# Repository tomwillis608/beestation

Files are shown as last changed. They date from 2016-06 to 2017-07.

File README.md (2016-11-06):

# beestation
Repo for wireless bee monitoring station experiments.

Currently embarassing hacking at simple Arduino and LAMP projects.  My first Arduino project.

ardunio/ - contains sketch for listening to sensors and sending the readings back to a PHP over WiFi.
server/ - contains php and mysql to use on your LAMP server

Done:
 * Add hardware watchdog circuit based on 555 chip. Something between my wireless network and the TCP connect calls locks up 5x a day.
 * Add multiple One-Wire sensors

To Do:
 * Add power-saving features
 * Add audio level and pitch sensors
 * Add weight sensors

Pondering
 * Add camera facing hive entrance 

-Tom Willis
Hacking Arduino for bees

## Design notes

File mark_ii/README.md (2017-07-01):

**beestation**

Repo for wireless bee monitoring station **Mark II** experiments.

*LAMP* folder for backend PHP and SQL manipulation of the data, plus web discplay of the data
*pi* folder for Raspberry Pi middle layer, receiving RF transmissions from the probes and sending data via HTTP to the LAMP backend
*arduino* folder for sketches, diagrams and pix about the wireless measurement probes

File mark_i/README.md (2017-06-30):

**beestation**

Repo for wireless bee monitoring station **Mark I** experiments.

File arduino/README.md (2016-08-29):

# beestation/arduino

Arduino sketch for wireless beehive monitoring station experiments

Currently embarassing hacking at simple Arduino and LAMP projects

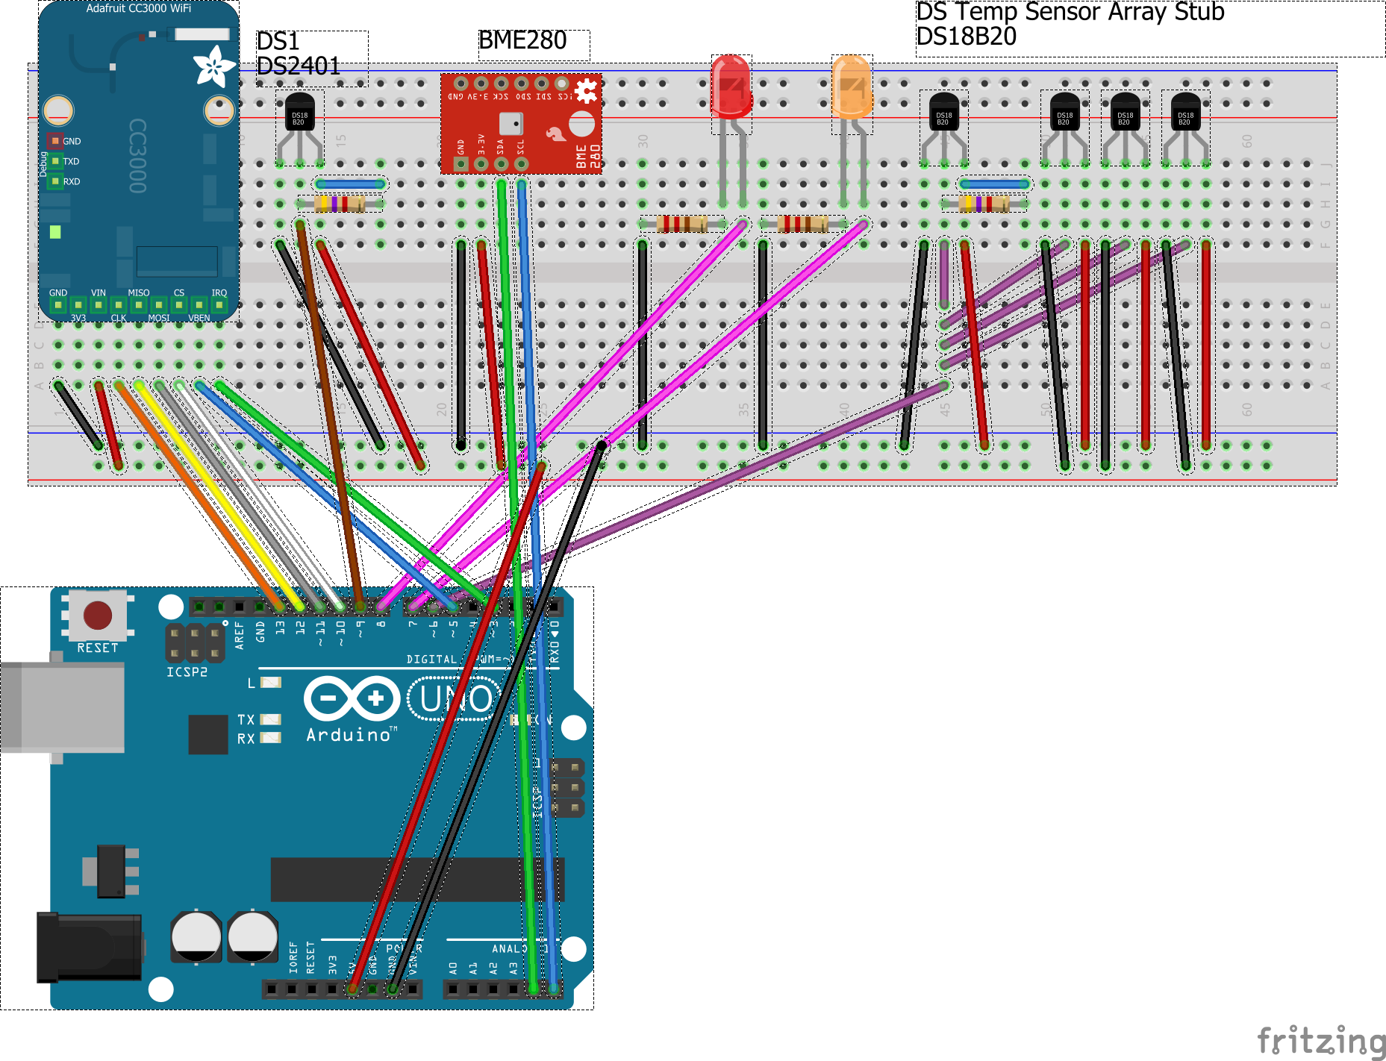
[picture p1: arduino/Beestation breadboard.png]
[]

beestation.ino - contains sketch for listening to a sensor and sending the readings back to a PHP over WiFi

beestation_breadboard.png - Frizing breadboard diagram for the kit (Note, I am actually using an Adafruit BME280 breakout, not the Sparkfun one shown in the image.

You must create your own MyCommon/mynetwork.h file that defines your own network secrets in your Arduino libraries folder. This must contain these macros, with the dummy values replaced with your own.
```C++
// Mynetwork.h
#define WEB_SERVER_IP_COMMAS 192, 168, 1, 1
#define WEB_SERVER_IP_DOTS   "192.168.1.1"
#define WLAN_SSID       "Your Network SSID"
#define WLAN_PASS       "Your Network Passcode"
```

I'm using the Visual Micro extension for Visual Studio because I like single-step debugging but you can use the sketch without all the Visual Studio clutter.

## THANKS:
Thanks to Marc-Oliver Schwartz for this excellent walkthrough of creating an Arduino weather station, with testing as you go.  I based much of this on his example. 
https://www.openhomeautomation.net/arduino-wifi-cc3000/
https://learn.adafruit.com/wifi-weather-station-arduino-cc3000/introduction

## Sensors:
* BME280 - Pressure, Humidity and Temperature. This will be measured outside the hive, at the board.
* DS2401 - Silicon serial number.  Unique ID for this kit. 

## Hardware watchdog
* NE555-based watchdog timer added to reset the Arduino if any of the code locks up
  
## To do:
* Add DS18B20 temperature sensors, in beeproof sleeves, to measure inside the hive
* Build hive sound volume level meter, in beeproof sleeve
* Harden wireless code
* Use built-in WTD watchdog for power-saving sleep
* On server end, collect local temperature and pressure from WU or other API as control values

-Tom Willis

Hacking Arduino for bees

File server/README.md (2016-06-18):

# beestation/arduino/server

PHP and MySQL for wireless bee monitoring station experiments

Currently embarassing hacking at simple Arduino and LAMP projects

php - php scripts to add sensor data to the tables and to display the data
mysql - MySQL code to create the tables needed to store the data

-Tom Willis
Hacking Arduino for bees

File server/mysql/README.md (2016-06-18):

# beestation/arduino/server/mysql

MySQL commands for wireless bee monitoring station experiments

Currently embarassing hacking at simple Arduino and LAMP projects

create_sensor_table.mysql - command to create the 'dht22' table for recording temperature and humidity sensor readings 

create_info_table.mysql - command to create the 'beestation' table for recording information about the monitoring station itself, e.g. when it starts up 

-Tom Willis
Hacking Arduino for bees

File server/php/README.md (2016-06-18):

# beestation/arduino/server/php

PHP scripts for wireless bee monitoring station experiments

Currently embarassing hacking at simple Arduino and LAMP projects

The add_* PHP scripts are called by the Arduino monitoring station to record data in MySQL tables

add_info.php - Add startup information about the monitoring station to the database
add_data.php - Add sensor data from the monitoring station to the database

The view_* PHP scripts are useful for viewing the data in a simple way

view_info.php - See the data about the monitoring station behavior
view_data.php - See the sensor data collected from the monitoring station

All of the four scripts above include "dbconnect.php", which contains database secrets.

You must create your own dbconnect.php file that defines your own database secrets, using the dbconnect_template.php as an example, to define your MySQL username, password, server and database name.

-Tom Willis
Hacking Arduino for bees

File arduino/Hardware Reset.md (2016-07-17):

# Hardware reset watchdog timer for Arduino

Somewhere in the interaction of my wireless network, which has some instabilities I have not yet sorted out, and the CC3300 WiFi on my Arduino beestation, I am getting lockups of the sketch, typically in the TCP conenct calls.  This seems to happend about four times a day, on average. The built-in AVR watch dog timer does not consistently reset the Arduino when this happens.  I decided to add a hardware watchdog to suppliment and perhaps replace the built-in AVR watchdog.  (TO DO: repurpose the AVR WTD to put the system to sleep in between measurements to conserve power.)

Thankfully, there are several useful articles on creating a hardware watchdog using a NE555 timer chip, including:
* http://www.practicalarduino.com/news/id/471
* http://forum.arduino.cc/index.php?topic=55041.0
* http://arduino.stackexchange.com/questions/7994/resetting-an-arduino-with-a-timer
* https://github.com/mattbornski/Arduino-Watchdog-Circuit
* https://www.circuitlab.com/circuit/cc9d7s/arduino-555-watchdog-circuit/
* http://www.playwitharduino.com/?p=291

I followed the cicruit design from http://www.playwitharduino.com/?p=291 and experimented with different capacitor values for C1, which changed the charge time as predicted by the forumlas provided in that article. I ended up settling with the 220uF suggested by the author since it was long enough but not as long at the 470uF provided. 

One of several 555 calculators is here: http://www.csgnetwork.com/ne555timer2calc.html

The 555 chip is new to me, so I enjoyed reading the 555 site http://www.555-timer-circuits.com/, especially the FAQ at http://www.555-timer-circuits.com/common-mistakes.html

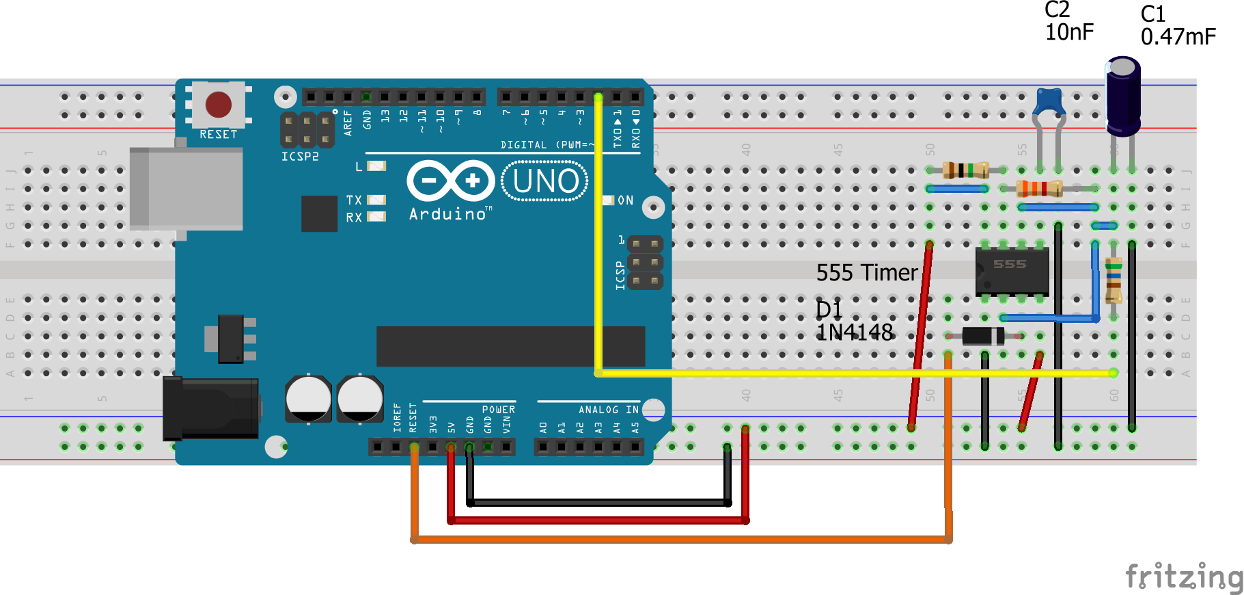
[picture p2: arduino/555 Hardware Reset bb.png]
[]

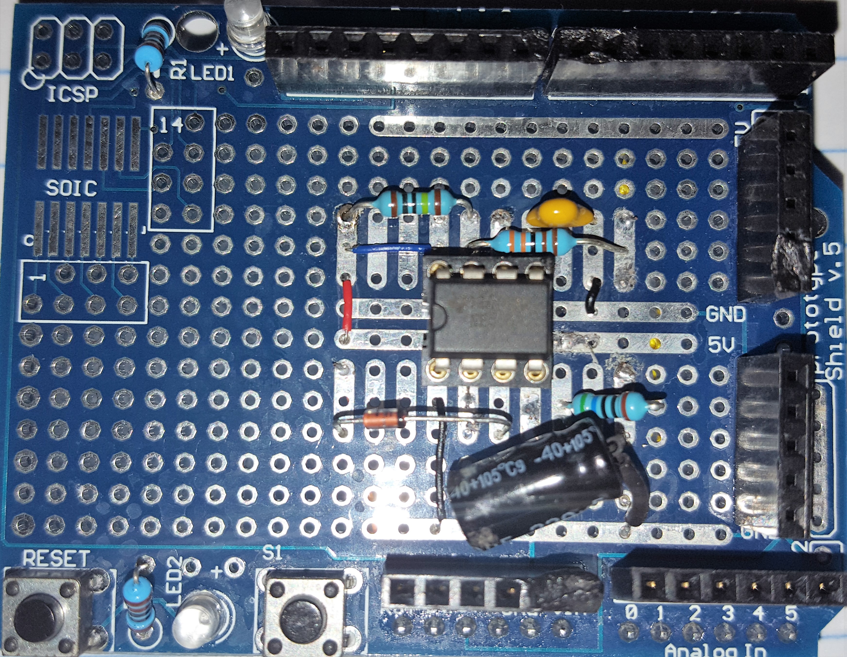
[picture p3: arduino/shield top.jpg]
[]

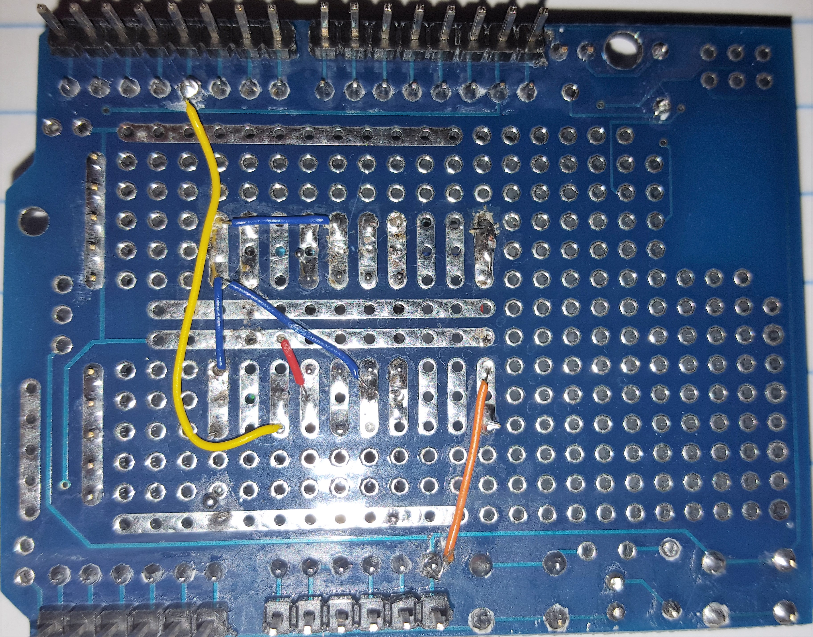
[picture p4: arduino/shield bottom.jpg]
[]

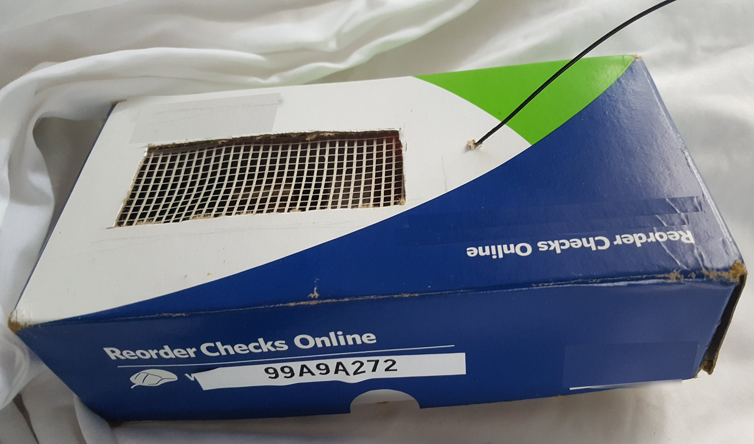
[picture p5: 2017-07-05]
mark_ii/prototype in-hive container for probes.jpg

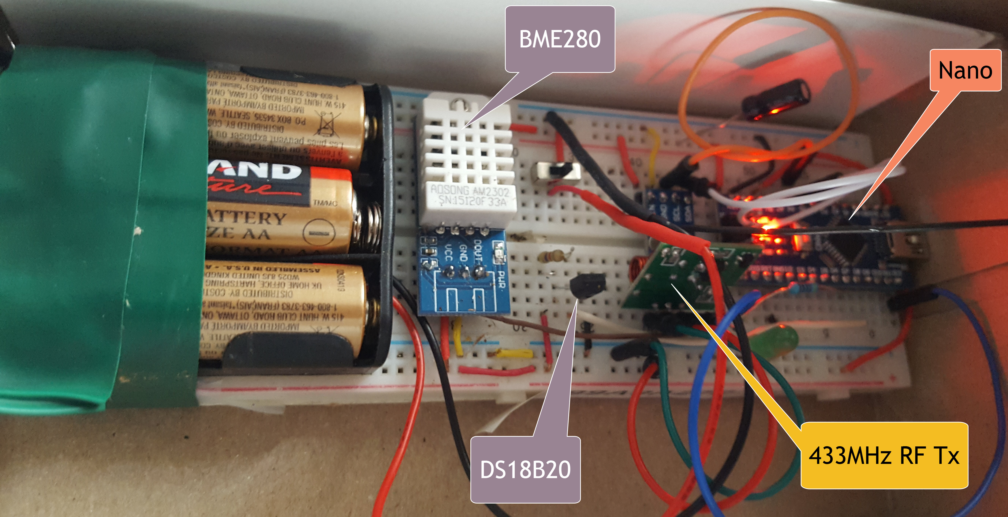
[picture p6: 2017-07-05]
mark_ii/Mark II Multiprobe Tx.jpg

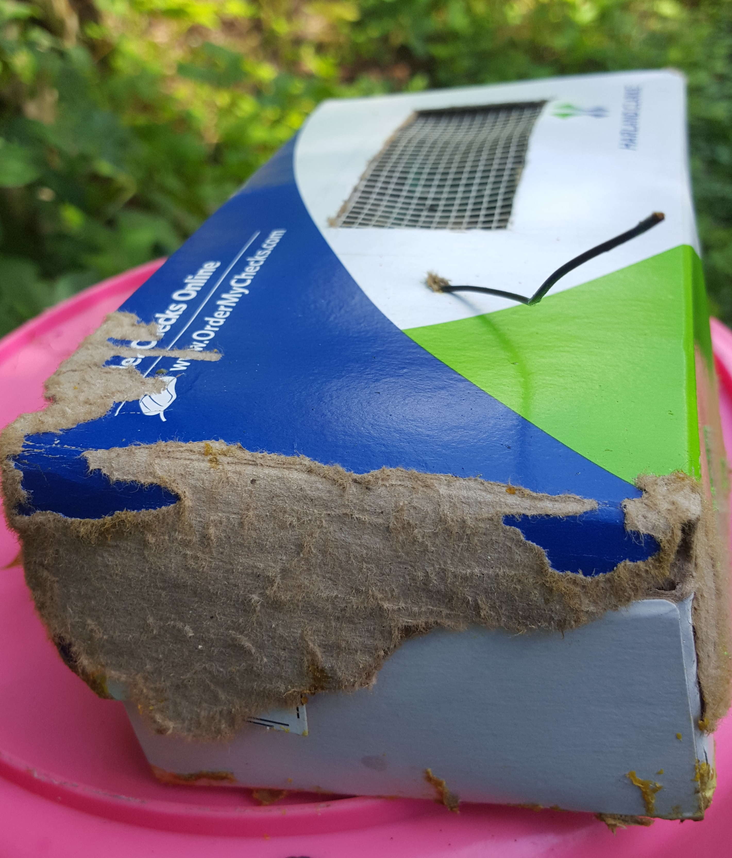
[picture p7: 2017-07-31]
mark_ii/mark ii nibbles.jpg

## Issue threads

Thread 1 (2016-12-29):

System doesn't work when temperature less than 0 degrees Celcius

tomwillis608, 2016-12-29:
When the temperature of the beehive drops below freezing, the system constantly reboots, connects to the web server but never reports and temperature measurements.

tomwillis608, 2016-12-29:
The temperature conversion routine for the DS18B20 sensors does not take into account the sign bit.

Closed 2016-12-29.

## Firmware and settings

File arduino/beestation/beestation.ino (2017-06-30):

/*
*  WiFi beekeeping monitor station with Arduino,
*  BME 280 temperature-pressure-humidity sensor,
*  Maxim DS2401 silicon serial number,
*  Maxim DS18B20 temperature sensors,
*  & the CC3000 chip WiFi.
*
*  Part of the code is based on the work done by Adafruit on the CC3000 chip & the DHT11 sensor.
*  Based in part on dht11/cc3300 weatherstation written by Marco Schwartz for Open Home Automation.
*  Based in part on OneWire/DS18B20 sample code from the OneWire library.
*  Lots of ideas taken from the many helpful posts in the community online.
*
*  Purpose:
*   Sends data to LAMP backend with HTTP GETs
*   Be stable over all conditions (Hardware reset cicruit currently required)
*
*  To Do:
*   More sensors, besides temperature. <<In Progress>>
*   Better network recovery code - I saw some ideas online
*   Powersaving by sleeping instead of waiting
*   Reduce code size
*
*/

#define USE_DHT 0
#define USE_CC3300 01
#define USE_DS2401 1
#define USE_DS18B20 1
#define USE_BME 1
#define MY_DEBUG 0

// Include required libraries
#include <Adafruit_CC3000.h> // wifi library
#include <SPI.h> // how to talk to adafruit cc3300 board
#include <OneWire.h> // PJRC OneWire library to read DS 1-Wire sensors, like DS2401 and DS18B20
					 // http://www.pjrc.com/teensy/td_libs_OneWire.html
#if USE_BME 
// Using I2C protocol
#include <Adafruit_BME280.h>
#endif // USE_BME

#include <avr/wdt.h> // Watchdog timer

#include <mynetwork.h> // defines network secrets and addresses
// WLAN_SSID
// WLAN_PASS
// WEB_SERVER_IP_COMMAS 
// WEB_SERVER_IP_DOTS 

// WiFi network 
#define WLAN_SECURITY   WLAN_SEC_WPA2

// Define CC3000 chip pins (WiFi board)
#define ADAFRUIT_CC3000_IRQ   3
#define ADAFRUIT_CC3000_VBAT  5
#define ADAFRUIT_CC3000_CS    10

// DS2401 bus pin
#define DS2401PIN 9
#define DS18B20PIN 6

// Create global CC3000 instance
Adafruit_CC3000 gCc3000 = Adafruit_CC3000(ADAFRUIT_CC3000_CS,
	ADAFRUIT_CC3000_IRQ,
	ADAFRUIT_CC3000_VBAT,
	SPI_CLOCK_DIVIDER);

#if USE_BME
Adafruit_BME280 gBme280; // I2C
// Variables to be exposed 
int gHumidity = 0;
int gPressure = 0;
int gTemperature = 0; 
#endif // USE_BME

#if USE_DS18B20
OneWire gDs(DS18B20PIN);
int gDevices;
#define DS_COUNT 10
byte gDsAddrs[DS_COUNT][8];
// Use array for DS18B20 temperatures and simplify HTTP printout code
int gDsTemps[DS_COUNT];
#endif // USE_DS18B20

// PHP server on backend
const char gWebServer[] = WEB_SERVER_IP_DOTS; // IP Address (or name) of server to dump data to 
#define WEB_PORT 80
uint32_t gIp;

//unsigned long gTimeNow;
unsigned long gCycles = 0;

// Serial Number of this beestation 
char gSerialNumber[3]; // read from Maxim DS2401 on pin 9, use rightmost word

const int gRedLED = 8; // LED on pin
const int gYellowLED = 7; // LED on pin 7

void setup(void)
{
	wdt_disable();
	// Blink LED
	pinMode(gRedLED, OUTPUT);
	pinMode(gYellowLED, OUTPUT);
	digitalWrite(gYellowLED, HIGH);
	digitalWrite(gRedLED, HIGH);
	delay(500);
	digitalWrite(gRedLED, LOW);

	// Start Serial
	Serial.begin(115200); // 9600
	Serial.print(F("\n\nInitializing BeeStation #"));

	// DS2401
	readSerialNumber(); // Populate gSerialNumber
	printFreeRam();
#if USE_DS18B20 
	setupDs18B20();
#endif // USE_DS18B20 

#if USE_BME
	// Initialize BMP180 sensor
	if (!gBme280.begin())
	{
		Serial.print(F("Cannot read BME280 sensor!"));
		while (1);
	}
#endif // USE_BME

	printFreeRam();

#if USE_CC3300
	setupCc3000();
	displayConnectionDetails();
#endif // USE_CC3300
	delay(2000);
#if USE_CC3300
	gIp = gCc3000.IP2U32(WEB_SERVER_IP_COMMAS);
	Serial.print(F("Connecting to web server "));
	gCc3000.printIPdotsRev(gIp);
	Serial.println();
	postStatusToWeb(gIp, "Start");
#endif
	Serial.println(F("Looping"));
	digitalWrite(gYellowLED, LOW);
	wdt_enable(WDTO_8S); // options: WDTO_1S, WDTO_2S, WDTO_4S, WDTO_8S
}

void loop(void)
{
	wdt_reset();
	resetHardwareWatchdog();
	gCycles++;
	Serial.print(F("Cycles:"));
	Serial.println(gCycles);
	printFreeRam();

#if USE_BME
	// Measure from BMP180 
	measureBme280();
	// As I suspected, the temperature reading on the particular BME280 sensor is high about 1 degree C
	// compared to other temperature measurements - 29 Aug 2016 TCW
	wdt_reset();
#endif

#if USE_DS18B20
	measureDs18B20();
	wdt_reset();
#endif // USE_DS18B20

#if USE_CC3300
	Serial.println(F("Connecting to web server"));
	wdt_reset();
	postReadingsToWeb(gIp); 
	wdt_reset();
	if (0 == (gCycles % 100)) {
		char message[64];
		char iBuf[12];
		strlcpy(message, itoa(gCycles, iBuf, 10), 64);
		strlcat(message, ("%20cycles"), 64);
		postStatusToWeb(gIp, message);
	}
	wdt_reset();
	// Check WiFi connection, reset if connection is lost
	checkAndResetWifi();
#endif // USE_CC3300
	wdt_reset();
	delayBetweenMeasurements(70); // Wait about a minute between measurements.
}

bool
displayConnectionDetails(void)
{
	uint32_t ipAddress, netmask, gateway, dhcpserv, dnsserv;

	if (!gCc3000.getIPAddress(&ipAddress, &netmask, &gateway, &dhcpserv, &dnsserv))
	{
		Serial.println(F("Can't get IP"));
		return false;
	}
	else
	{
		Serial.print(F("IP: ")); gCc3000.printIPdotsRev(ipAddress);
		Serial.println(F("\nGateway: ")); gCc3000.printIPdotsRev(gateway);
		return true;
	}
}

#define MILLISEC_IN_A_SECOND 1000
// take a little nap between measurements
void
delayBetweenMeasurements(int delaySeconds)
{
	for (int i = 0; i < delaySeconds; i++) {
		wdt_reset();
		delay(MILLISEC_IN_A_SECOND);
	}
}


#define OUTSTRSIZE 256
// send sensor measurements to the webserver
void
postReadingsToWeb(uint32_t ip)
{
	// Build the URL string
	char outStr[OUTSTRSIZE];
	char itoaBuf[12];

	strlcpy(outStr, ("GET /add_data.php?"), OUTSTRSIZE);
	strlcat(outStr, ("sn="), OUTSTRSIZE);
	strlcat(outStr, (gSerialNumber), OUTSTRSIZE);
	strlcat(outStr, ("&"), OUTSTRSIZE);
#if USE_BME
	strlcat(outStr, ("t1="), OUTSTRSIZE);
	itoa(gTemperature, itoaBuf, 10);
	strlcat(outStr, (itoaBuf), OUTSTRSIZE);
	strlcat(outStr, ("&"), OUTSTRSIZE);
	strlcat(outStr, ("hu="), OUTSTRSIZE);
	itoa(gHumidity, itoaBuf, 10);
	strlcat(outStr, (itoaBuf), OUTSTRSIZE);
	strlcat(outStr, ("&"), OUTSTRSIZE);
	strlcat(outStr, ("pr="), OUTSTRSIZE);
	itoa(gPressure, itoaBuf, 10);
	strlcat(outStr, (itoaBuf), OUTSTRSIZE);
#endif // USE_BME
	/* Write DS18B20 results */
#if USE_DS18B20
	for (int j = 0; j < DS_COUNT; j++) {
		strlcat(outStr, ("&t"), OUTSTRSIZE);
		itoa((j+2), itoaBuf, 10);
		strlcat(outStr, (itoaBuf), OUTSTRSIZE);
		strlcat(outStr, ("="), OUTSTRSIZE);
		itoa(gDsTemps[j], itoaBuf, 10);
		strlcat(outStr, (itoaBuf), OUTSTRSIZE);
	}
#endif
	Serial.println(outStr);
	postToWeb(ip, outStr);
}

// Send startup or other message about the station to the webserver
void
postStatusToWeb(uint32_t ip, const char * message)
{
	// Build the URL string
	char outStr[OUTSTRSIZE];
	strlcpy(outStr, ("GET /add_info.php?"), OUTSTRSIZE);
	strlcat(outStr, ("serial="), OUTSTRSIZE);
	strlcat(outStr, (gSerialNumber), OUTSTRSIZE);
	strlcat(outStr, ("&"), OUTSTRSIZE);
	strlcat(outStr, ("message="), OUTSTRSIZE);
	strlcat(outStr, (message), OUTSTRSIZE);
	postToWeb(ip, outStr);
}

/// Connect to webserver and send it the urlString 
void
postToWeb(uint32_t ip, const char * urlString)
{
	Adafruit_CC3000_Client client;
	unsigned int gConnectTimeout = 2000;
	unsigned long gTimeNow;

	digitalWrite(gRedLED, HIGH);
	gTimeNow = millis();
	do {
		Serial.println(F("->connectTCP"));
		client = gCc3000.connectTCP(ip, WEB_PORT);
		Serial.println(F("<-connectTCP"));
		delay(20);
	} while ((!client.connected()) && ((millis() - gTimeNow) < gConnectTimeout));

	if (client.connected())
	{
		//Serial.println(F("Created client interface"));
		Serial.println(urlString);
		Serial.println(F("->")); //  Connected
		client.fastrprint(urlString);
		client.fastrprint(" HTTP/1.1\r\n");
		client.fastrprint("Host: ");
		client.fastrprint(gWebServer);
		client.fastrprint("\r\n");
		//client.fastrprint("Connection: close\r\n");
		client.fastrprint("User-Agent: Arduino Beestation/0.0\r\n");
		client.fastrprintln("\r\n");
		//client.fastrprintln("");
		delay(100);
		while (client.available()) {
			char c = client.read();
			Serial.print(c);
		}
		client.close();
		Serial.println(F("<-")); // Disconnected
	}
	else
	{ // you didn't get a connection to the server:
		Serial.println(F("--> connection failed/n"));
	} 
	digitalWrite(gRedLED, LOW);
}

bool
readSerialNumber(void)
{
	const char hex[] = "0123456789ABCDEF";
	byte i = 0, j = 0;
	boolean present;
	byte data;
	OneWire ds2401(DS2401PIN); // create local 1-Wire instance on DS2401PIN for silicon serial number ds2401

	present = ds2401.reset();
	if (present == TRUE) {
		//Serial.println(F("1-Wire Device present bus"));
		ds2401.write(0x33);  //Send READ data command to 1-Wire bus
		for (i = 0; i <= 7; i++) {
			data = ds2401.read();
			if (i == 7) {
				gSerialNumber[j++] = hex[data / 16];
				gSerialNumber[j++] = hex[data % 16];
			}
		}
		gSerialNumber[j] = 0;
		Serial.println(gSerialNumber);
	}
	else { //Nothing is connected in the bus 
  //Serial.println(F("No 1-Wire Device detected on bus"));
		strlcpy(gSerialNumber, "00", 3);
	}
	//Serial.print(F("Serial Number for this kit: "));
	return present;
}

#if USE_BME
void
measureBme280(void)
{
	float temperature;
	float pressure;
	float humidity;

	temperature = gBme280.readTemperature();
	wdt_reset();
	pressure = gBme280.readPressure() / 100.0F;
	wdt_reset();
	humidity = gBme280.readHumidity();

	gPressure = (int)(pressure + 0.5);
#if MY_DEBUG
	Serial.print(F("Pressure:    "));
	Serial.print(pressure);
	Serial.print(F(" hPa => "));
	Serial.println(gPressure);
#endif // MY_DEBUG

	gTemperature = (int)(temperature + 0.5);
#if MY_DEBUG
	Serial.print(F("Temperature: "));
	Serial.print(temperature);
	Serial.print(F(" C =>"));
	Serial.println(gTemperature);
#endif

	gHumidity = (int)(humidity + 0.5);
#if MY_DEBUG
	Serial.print(F("Humidity: "));
	Serial.print(humidity);
	Serial.print(F(" RH =>"));
	Serial.println(gHumidity);
#endif 
	wdt_reset();
}
#endif // USE_BME

void
setupCc3000(void)
{
	Serial.println(F("CC3000 setup..."));
	/* 5/4/17 hack - seems stable 6/30/17 TCW */
	gCc3000.reboot();
		Serial.println(F("CC3000 reboot initialize"));
		delay(500);
#if 01
if (!gCc3000.begin())
	{
		Serial.println(F("CC3000 failed initialize"));
		do { /* do nothing without reset, let the watchdog bite */ } while (1);
	}
	#endif
// cleanup profiles the CC3000 module
	if (!gCc3000.deleteProfiles())
	{
		Serial.println(F("CC3000 failed to delete old profiles"));
		do { /* do nothing without reset, let the watchdog bite */ } while (1);
	}

	// Connect to  WiFi network
	Serial.println(F("Connecting to WiFi"));
	gCc3000.connectToAP(WLAN_SSID, WLAN_PASS, WLAN_SECURITY);

	// Check DHCP
	int dhcpCount = 0;
	while (!gCc3000.checkDHCP())
	{
		delay(100);
		Serial.println(F("Trying WiFi again..."));
		if (++dhcpCount > 100) {
			do { /* do nothing without reset, let the watchdog bite */ } while (1);
		}
	}
}

void
checkAndResetWifi(void)
{
	wdt_reset();
	if (!gCc3000.checkConnected() )
	{
		Serial.print(F("Time: "));
#if 0
		gTimeNow = millis();
		//prints time since program started
		Serial.println(gTimeNow);
#endif
		Serial.println(F("Lost WiFi. Rebooting CC3000"));
		gCc3000.disconnect();
		gCc3000.stop();
		wdt_reset();
		gCc3000.reboot(0);
		// setupCc3000() was rarely finishing before the watchdog bites, so let it
		do { /* do nothing without reset, let the watchdog bite */ } while (1);
	}
}

int
calculateFreeRam(void) {
	extern int __heap_start, *__brkval;
	int v;
	return (int)&v - (__brkval == 0 ? (int)&__heap_start : (int)__brkval);
}

// Feed the dog so it doesn't bite
void
resetHardwareWatchdog(void)
{
	pinMode(DD4, OUTPUT);
	delay(200);
	pinMode(DD4, INPUT);
}

// DS 18B20 Temperature sensor array

void
setupDs18B20(void)
{

	gDevices = countDsDevices(gDs);
	Serial.print(F("Found "));
	Serial.print(gDevices);
	Serial.println(F(" devices on bus"));
	for (int i = 0; i < gDevices; i++) {
		getDsAddrByIndex(gDs, gDsAddrs[i], i);
	}
}

int
countDsDevices(OneWire myDs)
{
	byte addr[8];
	int deviceCount = 0;

	myDs.reset();
	myDs.reset_search();
	while (myDs.search(addr)) {
		if (checkDsCrc(myDs, addr)) {
			deviceCount++;
		}
	}
	return deviceCount;
}

bool
checkDsCrc(OneWire myDs, byte addr[8])
{
	return (OneWire::crc8(addr, 7) == addr[7]);
}

bool
getDsAddrByIndex(OneWire myDs, byte firstadd[], int index)
{
	byte i;
	//	byte present = 0;
	byte addr[8];
	int count = 0;

	myDs.reset();
	myDs.reset_search();
	//Serial.print(F("OneWire @ "));
	//Serial.println(index);

	while (myDs.search(addr) && (count <= index)) {
		if ((count == index) && checkDsCrc(myDs, addr))
		{
			//Serial.print(F("Found addr: "));
			//Serial.print(F("0x"));
			for (i = 0; i < 8; i++) {
				firstadd[i] = addr[i];
				//if (addr[i] < 16) {
				//	//Serial.print(F("0"));
				//}
				//Serial.print(addr[i], HEX);
				//if (i < 7) {
				//	Serial.print(F(", "));
				//}
			}
			//Serial.println();
			return true;
		}
		count++;
	}
	return false;
}

// There are 10 DS12B80 sensors connected
// Three are in a linear probe that will go in the hive, above the first brood box, at 2, 6 and 10 inches spacing in a 12 inch tube
// Three more are in another linear probe that will go in the hive, above the second brood box, at 2, 6 and 10 inches spacing in a 12 inch tube
// Three more are in yet another linear probe that will go in the hive, aboce the first honey super, at 2, 6 and 10 inches spacing in a 12 inch tube
// There is one more mounted in the station near the BME280 sensor
void
measureDs18B20(void) {
	for (int i = 0; i < gDevices; i++) {
		int intTemp = getDsTempeature(gDs, gDsAddrs[i]);
#if MY_DEBUG 
		Serial.println(intTemp);
#endif	// MY_DEBUG
 // save some bytes over switch with cascading if's - ha ha
		if (0x67 == gDsAddrs[i][7]) {
			gDsTemps[1] = intTemp;
#if MY_DEBUG
			Serial.print(F("2in temp: "));
#endif
		}
		else if (0x36 == gDsAddrs[i][7]) {
			gDsTemps[2] = intTemp;
#if MY_DEBUG
			Serial.print(F("6in temp: "));
#endif
		}
		else if (0xC0 == gDsAddrs[i][7]) {
			gDsTemps[0] = intTemp;
#if MY_DEBUG
			Serial.print(F("box temp: "));
#endif
		}
		else if (0xB1 == gDsAddrs[i][7]) {
			gDsTemps[3] = intTemp;
#if MY_DEBUG
			Serial.print(F("10in temp: "));
#endif
		}
		else if (0xEC == gDsAddrs[i][7]) {
			gDsTemps[4] = intTemp;
#if MY_DEBUG
			Serial.print(F("2in temp2: "));
#endif
		}
		else if (0xDD == gDsAddrs[i][7]) {
			gDsTemps[5] = intTemp;
#if MY_DEBUG
			Serial.print(F("6in temp2: "));
#endif
		}
		else if (0x4D == gDsAddrs[i][7]) {
			gDsTemps[6] = intTemp;
#if MY_DEBUG
			Serial.print(F("10in temp2: "));
#endif
		}
		else if (0x6F == gDsAddrs[i][7]) {
			gDsTemps[7] = intTemp;
#if MY_DEBUG
			Serial.print(F("2in temp2: "));
#endif
		}
		else if (0x52 == gDsAddrs[i][7]) {
			gDsTemps[8] = intTemp;
#if MY_DEBUG
			Serial.print(F("6in temp2: "));
#endif
		}
		else if (0xAB == gDsAddrs[i][7]) {
			gDsTemps[9] = intTemp;
#if MY_DEBUG
			Serial.print(F("10in temp2: "));
#endif
		}
#if MY_DEBUG
		Serial.println(intTemp);
#endif
	}
}

// Testing shows 10-bit resolution give more than adequate precision and accuracy
int
getDsTempeature(OneWire myDs, byte addr[8])
{
	byte data[12];
	wdt_reset();

	// Get byte for desired resolution
	byte resbyte = 0x3F; // for 10-bit resolution

	// Set configuration
	myDs.reset();
	myDs.select(addr);
	myDs.write(0x4E);         // Write scratchpad
	myDs.write(0);            // TL
	myDs.write(0);            // TH
	myDs.write(resbyte);      // Configuration Register
	myDs.write(0x48);         // Copy Scratchpad
	myDs.reset();
	myDs.select(addr);

	//long starttime = millis();
	myDs.write(0x44, 1);         // start conversion
	while (!myDs.read()) {
		// do nothing
	}
#if MY_DEBUG1
	Serial.print(F("Conversion took: "));
	Serial.print(millis() - starttime);
	Serial.println(F(" ms"));
#endif // MY_DEBUG

	//delay(1000);     // maybe 750ms is enough, maybe not
	// we might do a ds.depower() here, but the reset will take care of it.
	wdt_reset();
	myDs.reset();
	myDs.select(addr);
	myDs.write(0xBE);         // Read Scratchpad


#if MY_DEBUG
	Serial.print(F("Raw Data: "));
#endif // MY_DEBUG
	for (int i = 0; i < 9; i++) {           // we need 9 bytes
		data[i] = myDs.read();
#if MY_DEBUG
		Serial.print(data[i], HEX);
		Serial.print(F(" "));
#endif // MY_DEBUG
	}
#if MY_DEBUG
	Serial.println();
#endif // MY_DEBUG

	// convert the data to actual temperature
	int raw = (data[1] << 8) + data[0];
	// What about negative temps? 
	// look for sign bit per http://stackoverflow.com/questions/30646783/arduino-temperature-sensor-negative-temperatures
	int signBit = raw & 0x8000;  // test most sig bit
	if (signBit) { // negative
		raw = ((raw ^ 0xffff) + 1) * (-1); // 2's comp
	}
	int celsius_100 = (6 * raw) + raw / 4;    // multiply by (100 * 0.0625) or 6.25

	int whole = celsius_100 / 100;  // separate off the whole and fractional portions
	//int fraction = celsius_100 % 100;
#if MY_DEBUG
	Serial.print("Temp (C): ");
#endif // MY_DEBUG
	return whole;
	}

void
printFreeRam(void)
{
	Serial.print(F("Free:"));
	Serial.println(calculateFreeRam());
}

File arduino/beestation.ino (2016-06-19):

/*
*  WiFi beekeeping monitor station with Arduino, the DHT22 temperature and humidity sensor & the CC3000 chip WiFi.
*  Part of the code is based on the work done by Adafruit on the CC3000 chip & the DHT11 sensor
*  Based in part on dht11/cc3300 weatherstation written by Marco Schwartz for Open Home Automation
*  Lots of ideas taken from the many helpful posts in the community online.
*
*  Purpose:
*  Sends data to LAMP backend with HTTP GETs to reduce load from AREST which seemed to make the app unstable on Uno
*
*  To Do:
*   More sensors.
*   Better watchdogging - still seems to stop sending to the PHP server with MTF 36 hours
*   Better network recovery code - I saw some ideas online
*
*/

// Include required libraries
#include <Adafruit_CC3000.h> // wifi library
#include <SPI.h> // how to talk to adafruit cc3300 board
#include <DHT.h> // library to read DHT22 sensor
#include <OneWire.h> // library to read DS 1-Wire sensors, like DS2401 and DS18B20
#include <avr/wdt.h> // Watchdog timer

#include <mycommon/mynetwork.h> // defines network secrets and addresses
// WLAN_SSID
// WLAN_PASS
// WEB_SERVER_IP_COMMAS 
// WEB_SERVER_IP_DOTS 

// WiFi network 
#define WLAN_SECURITY   WLAN_SEC_WPA2

// Define CC3000 chip pins (WiFi board)
#define ADAFRUIT_CC3000_IRQ   3
#define ADAFRUIT_CC3000_VBAT  5
#define ADAFRUIT_CC3000_CS    10

// DHT22 sensor pins (temperature/humidy sensor)
#define DHTPIN 7 
#define DHTTYPE DHT22

// Create global CC3000 instance
Adafruit_CC3000 gCc3000 = Adafruit_CC3000(ADAFRUIT_CC3000_CS,
	ADAFRUIT_CC3000_IRQ,
	ADAFRUIT_CC3000_VBAT,
	SPI_CLOCK_DIV2);

// create global DHT instance
DHT gDht(DHTPIN, DHTTYPE);

// PHP server on backend
const char gWebServer[] = WEB_SERVER_IP_DOTS; // IP Address (or name) of server to dump data to 
#define WEB_PORT 80

unsigned long gTimeNow;

// Variables to be exposed 
int gTemperature;
int gHumidity;
int gConnectTimeout;
// Serial Number of this beestation 
char gSerialNumber[20]; // read from Maxim DS2401 on pin 9

void setup(void)
{
	wdt_disable();
	// Start Serial
	Serial.begin(9600); // 9600
	Serial.println(F("\n\nInitializing Bee Station"));
	readSerialNumber();

	// Initialize DHT22 sensor
	gDht.begin();

	// Initialise the CC3000 module
	if (!gCc3000.begin())
	{
		while (1);
	}
	// cleanup profiles the CC3000 module
	if (!gCc3000.deleteProfiles())
	{
		while (1);
	}

	// Connect to  WiFi network
	Serial.println(F("Connecting to WiFi"));
	gCc3000.connectToAP(WLAN_SSID, WLAN_PASS, WLAN_SECURITY);
	// Check DHCP
	while (!gCc3000.checkDHCP())
	{
		delay(100);
		Serial.println(F("Trying WiFi again..."));
	}
	displayConnectionDetails();
	uint32_t ip = gCc3000.IP2U32(WEB_SERVER_IP_COMMAS);
	Serial.print(F("About to connect to web server at "));
	gCc3000.printIPdotsRev(ip);
	Serial.println();
	postStatusToWeb(ip, "Start Bee Monitoring Station");
	Serial.println(F("Looping"));
	Serial.print(F("Time: "));
	gTimeNow = millis();
	//prints time since program started
	Serial.println(gTimeNow);
	gConnectTimeout = 1000;
	wdt_enable(WDTO_8S); // options: WDTO_1S, WDTO_2S, WDTO_4S, WDTO_8S
}

void loop(void)
{
	wdt_reset();

	delay(2);
	// Measure from DHT
	gTemperature = gDht.readTemperature();
	gHumidity = gDht.readHumidity();
	// Check if any reads failed and exit early (to try again).
	if (isnan(gTemperature) || isnan(gHumidity)) {
		Serial.print("Time: ");
		gTimeNow = millis();
		//prints time since program started
		Serial.println(gTimeNow);
		Serial.println("Cannot read DHT sensor!");
		return;
	}
	//wdt_reset();  

	Serial.print("H: ");
	Serial.print(gHumidity);
	Serial.print(" %\t");
	Serial.print("T: ");
	Serial.print(gTemperature);
	Serial.print(" *C ");

	wdt_reset();
	// if you get a connection, report back via serial:  
	uint32_t ip = gCc3000.IP2U32(WEB_SERVER_IP_COMMAS);
	Serial.print("About to connect to web server ");
	gCc3000.printIPdotsRev(ip);
	Serial.println();
	// Optional: Do a ping test on the website
	//Serial.print(F("\n\rPinging ")); cc3000.printIPdotsRev(ip); Serial.print(F(" ... "));
	//uint16_t replies = cc3000.ping(ip, 5);
	//Serial.print(replies); Serial.println(F(" replies"));

	postReadingsToWeb(ip, gTemperature, gHumidity);

	// Check WiFi connection, reset if connection is lost
	checkAndResetWifi();

	wdt_reset();
	delayBetweenMeasurements(100); // Wait a few seconds between measurements.
}

bool
displayConnectionDetails(void)
{
	uint32_t ipAddress, netmask, gateway, dhcpserv, dnsserv;

	if (!gCc3000.getIPAddress(&ipAddress, &netmask, &gateway, &dhcpserv, &dnsserv))
	{
		return false;
	}
	else
	{
		Serial.println(F("\nIP Addr: ")); gCc3000.printIPdotsRev(ipAddress);
		Serial.print(F("\nNetmask: ")); gCc3000.printIPdotsRev(netmask);
		Serial.print(F("\nGateway: ")); gCc3000.printIPdotsRev(gateway);
		Serial.print(F("\nDHCPsrv: ")); gCc3000.printIPdotsRev(dhcpserv);
		Serial.print(F("\nDNSserv: ")); gCc3000.printIPdotsRev(dnsserv);
		Serial.println("");
		return true;
	}
}

#define ONETHOUSAND 1000
void
delayBetweenMeasurements(int delaySeconds)
{
	for (int i = 0; i < delaySeconds; i++) {
		wdt_reset();
		delay(ONETHOUSAND);
	}
}


#define OUTSTRSIZE 256
void
postReadingsToWeb(uint32_t ip, int temperature, int humidity)
{
	// Build the URL string
	char outStr[OUTSTRSIZE];
	char itoaBuf[12];
	strlcpy(outStr, ("GET /add_data.php?"), OUTSTRSIZE);
	strlcat(outStr, ("serial="), OUTSTRSIZE);
	strlcat(outStr, (gSerialNumber), OUTSTRSIZE);
	strlcat(outStr, ("&"), OUTSTRSIZE);
	strlcat(outStr, ("temperature="), OUTSTRSIZE);
	itoa(temperature, itoaBuf, 10);
	strlcat(outStr, (itoaBuf), OUTSTRSIZE);
	strlcat(outStr, ("&"), OUTSTRSIZE);
	strlcat(outStr, ("humidity="), OUTSTRSIZE);
	itoa(humidity, itoaBuf, 10);
	strlcat(outStr, (itoaBuf), OUTSTRSIZE);
	//Serial.println(outStr);
	postToWeb(ip, outStr);
}


void
postStatusToWeb(uint32_t ip, const char * message)
{
	// Build the URL string
	char outStr[OUTSTRSIZE];
	strlcpy(outStr, ("GET /add_info.php?"), OUTSTRSIZE);
	strlcat(outStr, ("serial="), OUTSTRSIZE);
	strlcat(outStr, (gSerialNumber), OUTSTRSIZE);
	strlcat(outStr, ("&"), OUTSTRSIZE);
	strlcat(outStr, ("message="), OUTSTRSIZE);
	strlcat(outStr, (message), OUTSTRSIZE);
	//Serial.println(outStr);
	postToWeb(ip, outStr);
}
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

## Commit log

2016-06-18 Adding initial Arduino sketch for my bee monitoring station. This repo does not contain the MyCommon/myNetwork.h header with my network secrets but you can make your own.
2016-06-18 Breadboard of the initial bee monitoring station, one temperature and humidity sensor only.
2016-06-19 Add silicon serial number with DS2401, so the board now has hardware serial number.
2016-06-21 Add pressure measurement, improve syntax of INSERT statement.
2016-06-22 1. Add support for pressure measurements 2. Add pagination
2016-06-23 Swapped out BHT22 and BMP180 sensors for one BME280 sensor for the on-board pressure, temperature and humidity readings.
    [beestation.ino]
2016-06-23 Swapped out BHT22 and BMP180 sensors for one BME280 sensor for the on-board pressure, temperature and humidity readings in this corrected PNG.
2016-07-17 Update sketch and notes with the code that has been running for the last few weeks, including the hardware watchdog timer. Initially, I was reluctant to use a hardware watchdog, but between my networ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
2016-07-19 Add indicator LEDs to the breadboard graphic, with current-limiting resistors. (lost one - doh!)
2016-08-30 Added DS18B20 temperature sensors to the monitoring station. Make those measurements and send the data back to the web server. Shorten the attribute names in the attr-value pairs sent to the web serv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
    [beestation.ino]
2016-11-06 Added two more linear sensors of 3 temperature probes each, above sucessive boxes in the hive.
2016-11-25 Update add_data.php
    Update PHP to load data from the new 3-sensor probes that site at various heights in the beehive.
2016-11-25 Update review_data.php
    Update PHP to display the new temperature sensor data from the new probes over the lower boxes in the beehive.
2016-12-29 Modify getDsTempeature() to work in integers and measureDs18B20() to get an integer temperature. Fix getDsTempeature() to honor the sign bit in the DS18B20 hex array. Resolves #1.
    [lm386 amplifier.fzz]
2017-03-10 Fix typo in comment
    [beestation.ino]
2017-06-30 Create README.md
    Creating mark_ii folder for second round of beestation experiments - 433MHz RF Arduino to Raspberry Pi to LAMP backend.
2017-07-01 Create add_record.php
    Add simple PHP for Mark II beestation to record the measurements of the various probes
2017-07-01 Create rftest.py
    Temporary Raspberry Pi hack for capturing 433MHz RF transmissions from various Arduinos sending measurements (P, T, RH, voltage, ...) and sending status and measurements to the LAMP backend, for Mark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
2017-07-05 Add files via upload
    Photos of Mark II prototype for multi-sensor, in-hive, wireless, battery-powered probe.
2017-07-31 Mark I probes at work in opened hive
2017-07-31 Mark II prototype P, T, RH sensor in place
2017-07-31 Recent photo of Mark II prototype
    The bees have nibbled at the cardboard box holding the Mark II prototype.
